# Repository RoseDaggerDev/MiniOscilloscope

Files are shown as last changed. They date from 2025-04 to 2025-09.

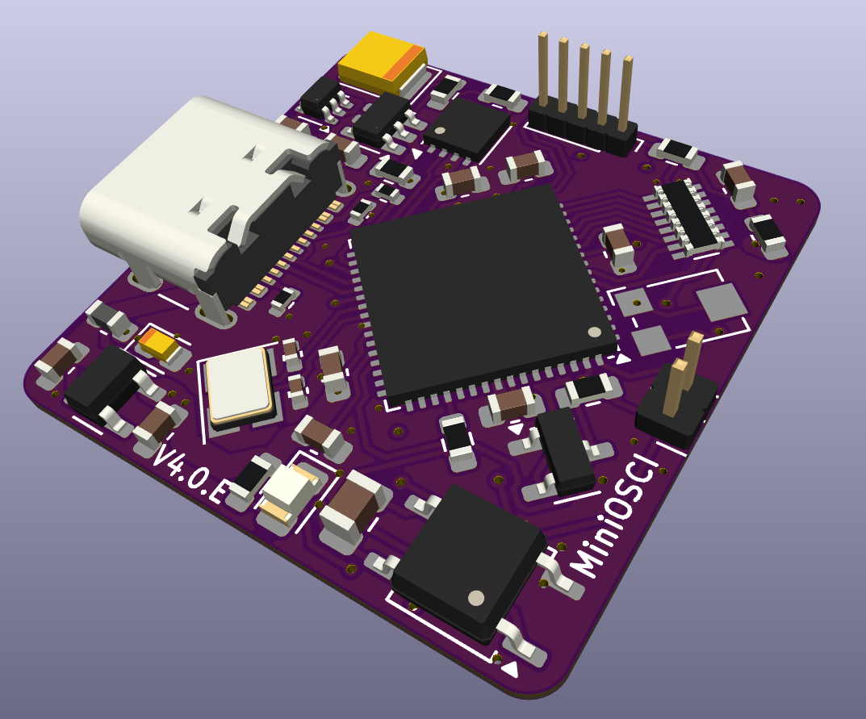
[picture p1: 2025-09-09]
KiCAD/Images/TopRender.png

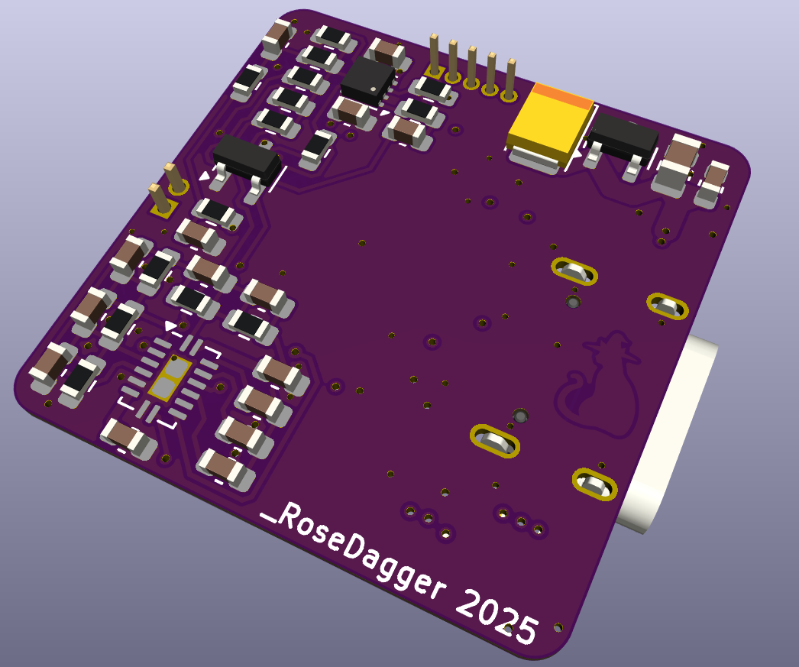
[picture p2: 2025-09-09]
KiCAD/Images/BottomRender.png

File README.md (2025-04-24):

# MiniOscillscope
This is a little hobby project, taking the EDU09 digital oscilloscope kit from Velleman and redesigning it. I made a through-hole version using the same components as the Velleman kit. And a SMD version using all original parts.

Through-Hole Version: Its been fully tested and works like a charm. Its got a BOM of 87 components and fits on a 50x50mm 2-layer board, manufactured by PCBWay. It took around 3.5 hours to solder after prepping all the components. I underestimated the IC socket size, so things got a bit tight with some parts had to be nudged sideways. I also used the wrong footprint size for the ceramic caps, so they’re a little squished, but everything still worked out in the end!

SMD Version: The SMD version is a compact 25x25mm 4-layer board printed by JLCPCB. It has a BOM of 97 components, including 3 QFNs and four 0402-sized parts, the rest mostly 0603s and SOPs. It took me about 5 hours to solder under a digital microscope, using a hot air rework station and freehanded solder paste. There’s one visible bridge in the upper middle that I’ll clean up later. It’s not really an issue as those pins are already connected by a trace, but it will look cleaner. There’s also some solder blobbing that could be tidied up, but hey, it’s functional (or it will be).

Power rails are looking good, 5V and 3.3V are where they should be, and I’ve confirmed there are no shorts or open circuits on the test points. I haven’t flashed firmware yet because it turns out my old PicKit 3 is too old for the PIC I used, so I’m waiting on a new flasher before I can give it a real test.

Background: The through-hole version was a university project, while the SMD version was my own follow-up challenge. I reverse-engineered the component choices from the original Velleman oscilloscope kit, looking up datasheets and selecting alternatives with similar or improved specs. The original Velleman was around 100x100mm. My through-hole version shrank it to 50x50mm (¼ the size), and the SMD version again cut that down to 25x25mm, or just 1/16 the original footprint. Everything was designed in Proteus 5, since that’s what we use at university.

All in all, I’m really happy with how this turned out. It’s my first full SMD design and soldering job, and despite a few cosmetic hiccups, I think it came together nicely. The through-hole version could have looked neater, but given the part constraints of only using the Velleman kit parts, I’m proud of how compact I got it

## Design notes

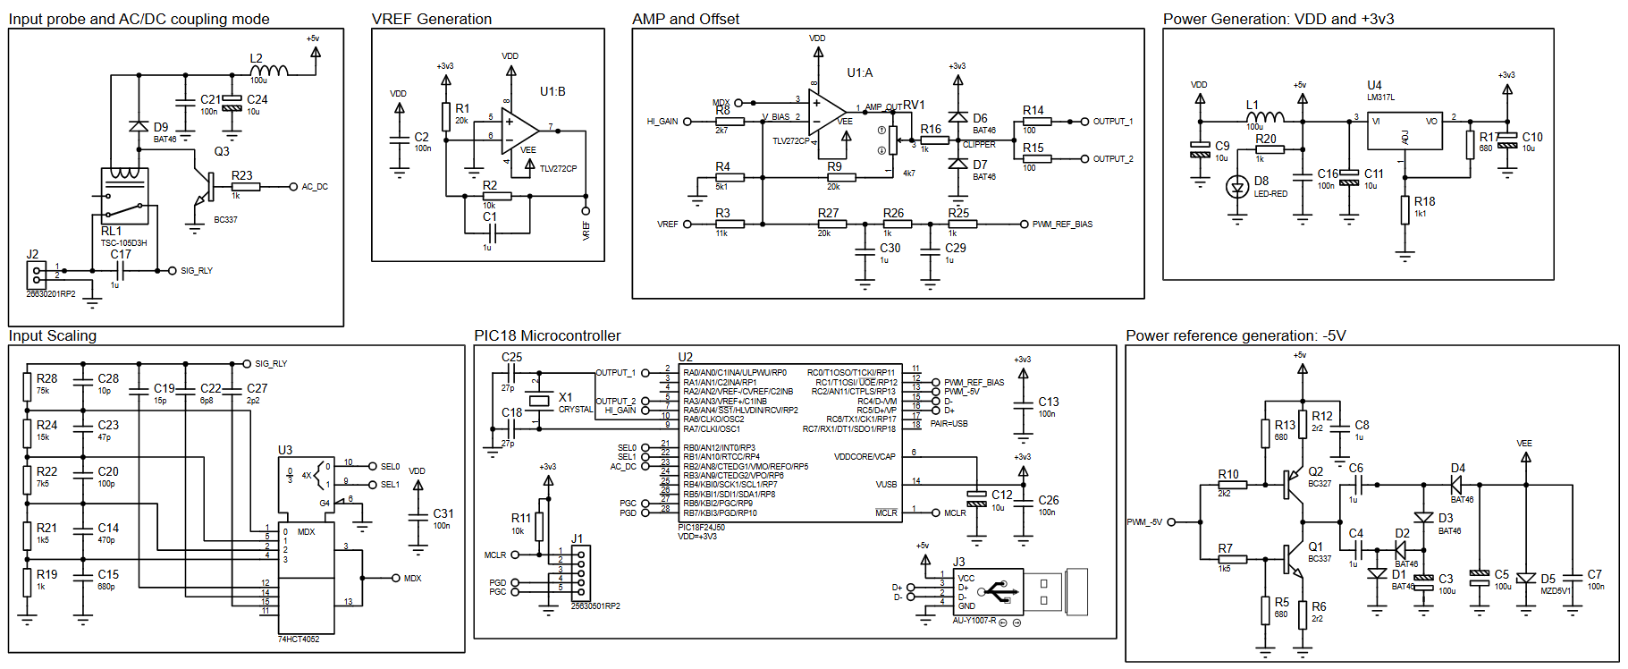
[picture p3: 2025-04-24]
Gloryshots/THT Schematic.png

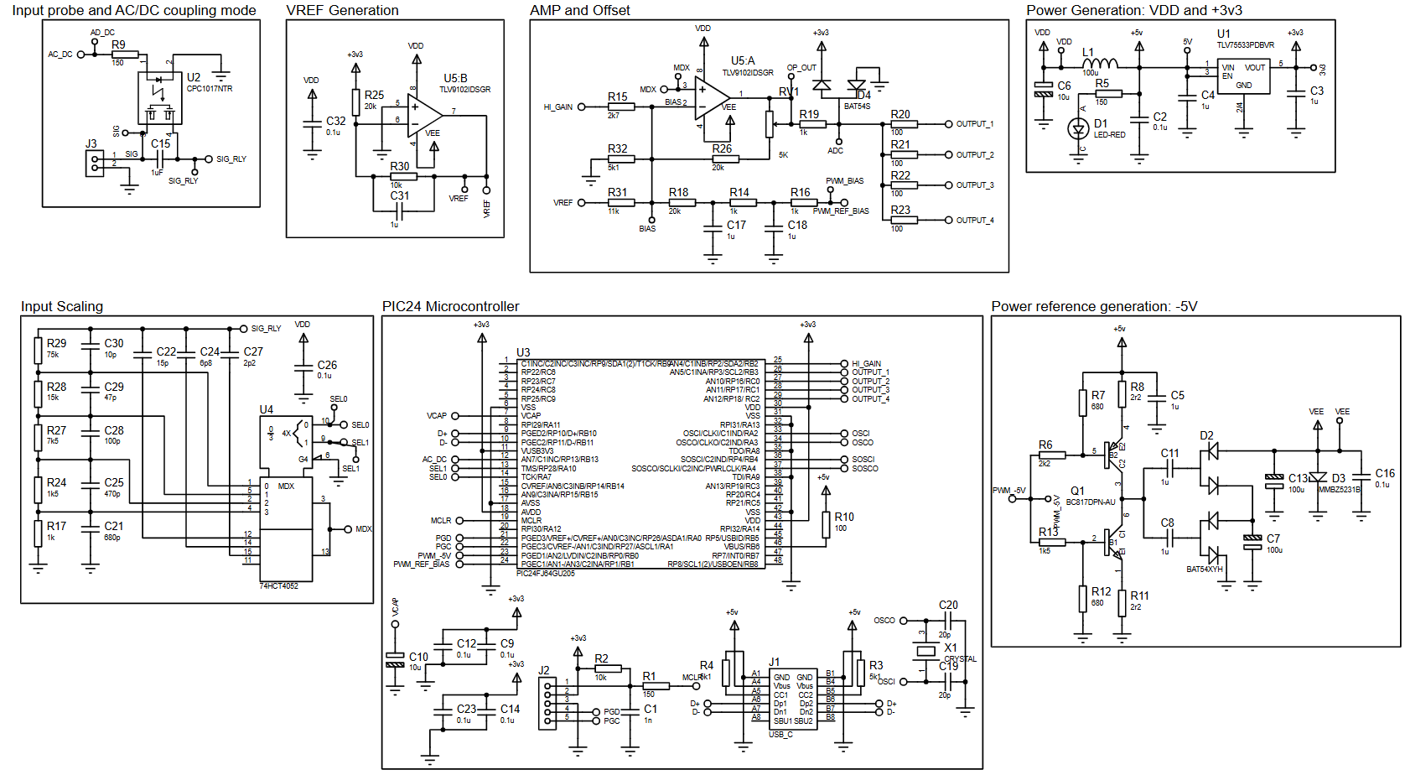
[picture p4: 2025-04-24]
Gloryshots/SMD Schematic.png

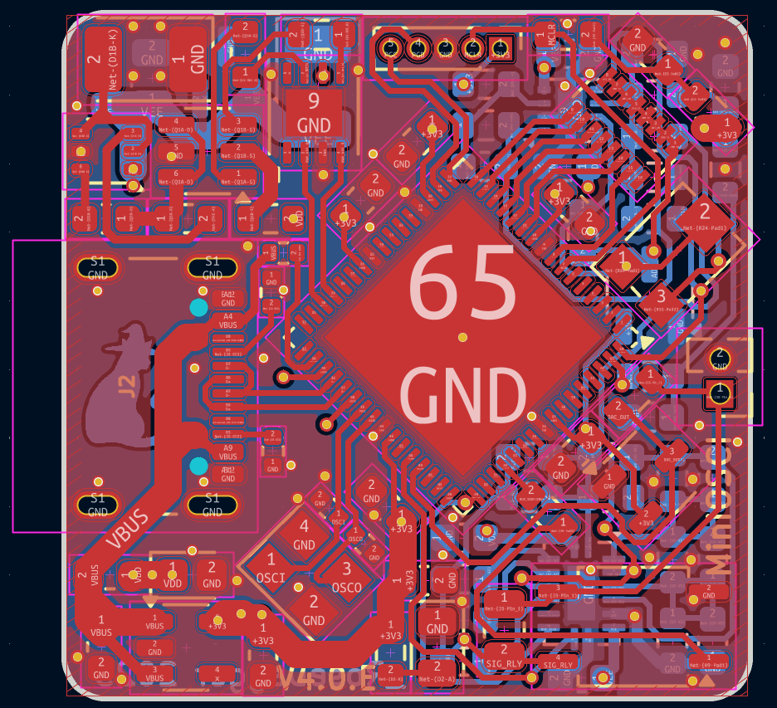
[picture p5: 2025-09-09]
KiCAD/Images/TraceView.png

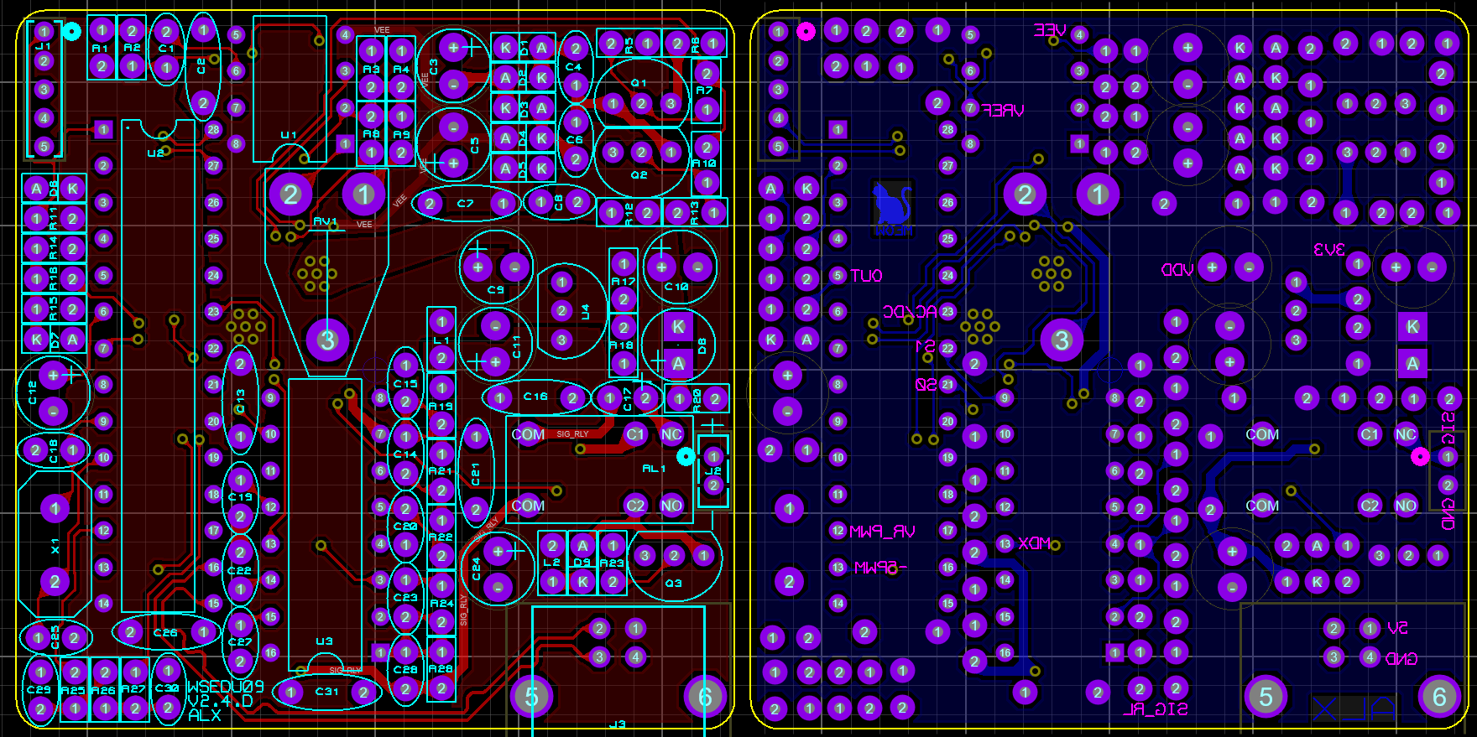
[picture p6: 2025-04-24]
Gloryshots/THT version front back.png

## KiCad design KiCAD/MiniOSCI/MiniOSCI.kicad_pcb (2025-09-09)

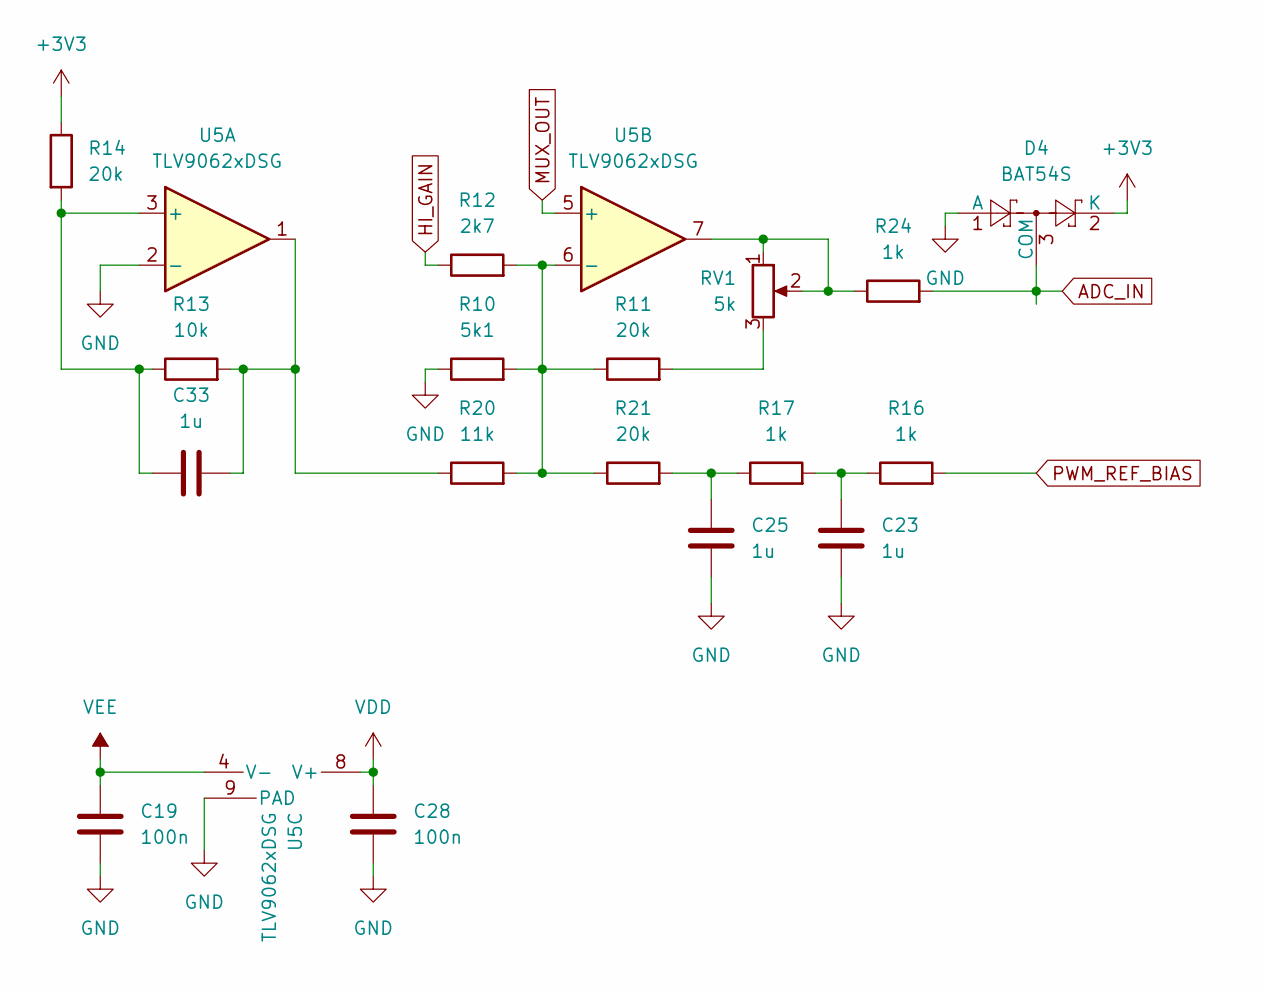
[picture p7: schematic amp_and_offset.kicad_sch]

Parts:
C19, C28: 100n; C_0603_1608Metric
C23, C25, C33: 1u; C_0603_1608Metric
D4: BAT54S; SOT-23-3
R10: 5k1; R_0603_1608Metric
R11, R14, R21: 20k; R_0603_1608Metric
R12: 2k7; R_0603_1608Metric
R13: 10k; R_0603_1608Metric
R16, R17, R24: 1k; R_0603_1608Metric
R20: 11k; R_0603_1608Metric
RV1: 5k; Potentiometer_Bourns_TC33X_Vertical
U5: TLV9062xDSG; WSON-8-1EP_2x2mm_P0.5mm_EP0.9x1.6mm

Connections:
+3V3: D4.2 (K), R14.1; also elsewhere on the board
ADC_IN: D4.3 (COM), R24.2; also elsewhere on the board
GND: C19.2, C23.2, C25.2, C28.2, D4.1 (A), R10.1, U5.2 (-), U5.9 (PAD); also elsewhere on the board
HI_GAIN: R12.1; also elsewhere on the board
MUX_OUT: U5.5 (+); also elsewhere on the board
unnamed: C23.1, R16.1, R17.2
unnamed: C25.1, R17.1, R21.2
unnamed: C33.2, R13.2, R20.1, U5.1
unnamed: R11.2, RV1.3
unnamed: R24.1, RV1.1, RV1.2, U5.7
unnamed: C33.1, R13.1, R14.2, U5.3 (+)
unnamed: R10.2, R11.1, R12.2, R20.2, R21.1, U5.6 (-)
PWM_REF_BIAS: R16.2; also elsewhere on the board
VDD: C28.1, U5.8 (V+); also elsewhere on the board
VEE: C19.1, U5.4 (V-); also elsewhere on the board

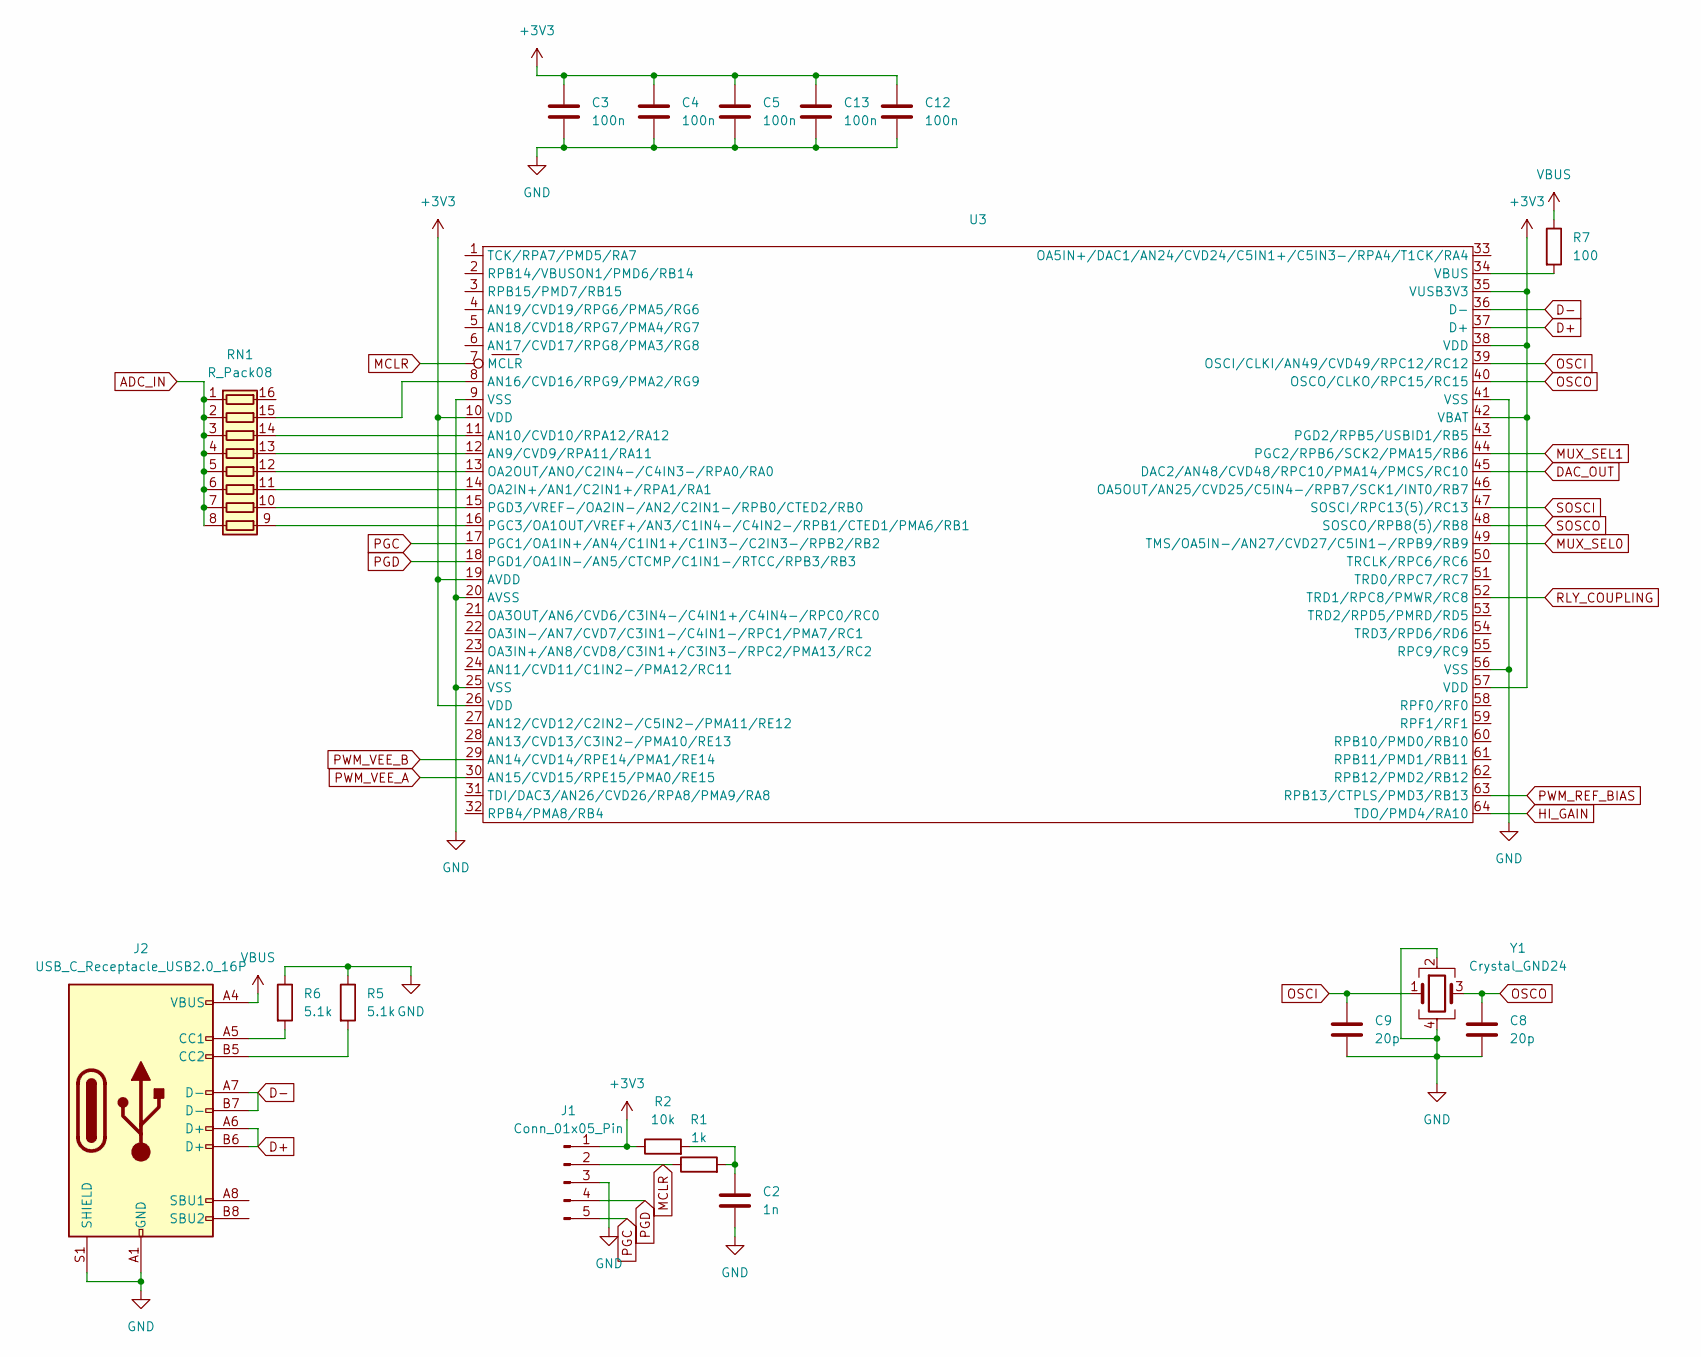
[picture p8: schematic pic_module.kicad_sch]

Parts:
C2: 1n; C_0603_1608Metric
C3, C4, C5, C12, C13: 100n; C_0603_1608Metric
C8, C9: 20p; C_0402_1005Metric
J1: Conn_01x05_Pin; PinHeader_1x05_P1.00mm_Vertical
J2: USB_C_Receptacle_USB2.0_16P; USB_C_Receptacle_GCT_USB4105-xx-A_16P_TopMnt_Horizontal
R1: 1k; R_0603_1608Metric
R2: 10k; R_0603_1608Metric
R5, R6: 5.1k; R_0402_1005Metric
R7: 100; R_0402_1005Metric
RN1: R_Pack08; R_Array_Convex_8x0602
U3: VQFN-64-1EP_9x9mm_P0.5mm_EP7.15x7.15mm
Y1: Crystal_GND24; Crystal_SMD_3225-4Pin_3.2x2.5mm

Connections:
+3V3: C3.1, C4.1, C5.1, C12.1, C13.1, J1.1, R2.1, U3.10 (VDD), U3.19 (AVDD), U3.26 (VDD), U3.35 (VUSB3V3), U3.38 (VDD), U3.42 (VBAT), U3.57 (VDD); also elsewhere on the board
ADC_IN: RN1.1 (R1.1), RN1.2 (R2.1), RN1.3 (R3.1), RN1.4 (R4.1), RN1.5 (R5.1), RN1.6 (R6.1), RN1.7 (R7.1), RN1.8 (R8.1); also elsewhere on the board
D+: J2.A6 (D+), J2.B6 (D+), U3.37 (D+)
D-: J2.A7 (D-), J2.B7 (D-), U3.36 (D-)
DAC_OUT: U3.45 (DAC2/AN48/CVD48/RPC10/PMA14/PMCS/RC10); also elsewhere on the board
GND: C2.2, C3.2, C4.2, C5.2, C8.2, C9.2, C12.2, C13.2, J1.3, J2.A1 (GND), J2.A12 (GND), J2.B1 (GND), J2.B12 (GND), J2.S1 (SHIELD), R5.1, R6.1, U3.9 (VSS), U3.20 (AVSS), U3.25 (VSS), U3.41 (VSS), U3.56 (VSS), U3.65, Y1.2, Y1.4; also elsewhere on the board
HI_GAIN: U3.64 (TDO/PMD4/RA10); also elsewhere on the board
MCLR: J1.2, R1.1, U3.7 (MCLR)
MUX_SEL0: U3.49 (TMS/OA5IN-/AN27/CVD27/C5IN1-/RPB9/RB9); also elsewhere on the board
MUX_SEL1: U3.44 (PGC2/RPB6/SCK2/PMA15/RB6); also elsewhere on the board
unnamed: C2.1, R1.2, R2.2
unnamed: J2.A5 (CC1), R6.2
unnamed: J2.B5 (CC2), R5.2
unnamed: RN1.15 (R2.2), U3.8 (AN16/CVD16/RPG9/PMA2/RG9)
unnamed: RN1.14 (R3.2), U3.11 (AN10/CVD10/RPA12/RA12)
unnamed: RN1.13 (R4.2), U3.12 (AN9/CVD9/RPA11/RA11)
unnamed: RN1.12 (R5.2), U3.13 (OA2OUT/ANO/C2IN4-/C4IN3-/RPA0/RA0)
unnamed: RN1.11 (R6.2), U3.14 (OA2IN+/AN1/C2IN1+/RPA1/RA1)
unnamed: RN1.10 (R7.2), U3.15 (PGD3/VREF-/OA2IN-/AN2/C2IN1-/RPB0/CTED2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)
unnamed: RN1.9 (R8.2), U3.16 (PGC3/OA1OUT/VREF+/AN3/C1IN4-/C4IN2-/RPB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)
unnamed: R7.2, U3.34 (VBUS)
OSCI: C9.1, U3.39 (OSCI/CLKI/AN49/CVD49/RPC12/RC12), Y1.1
OSCO: C8.1, U3.40 (OSCO/CLKO/RPC15/RC15), Y1.3
PGC: J1.5, U3.17 (PGC1/OA1IN+/AN4/C1IN1+/C1IN3-/C2IN3-/RP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)
PGD: J1.4, U3.18 (PGD1/OA1IN-/AN5/CTCMP/C1IN1-/RTCC/RPB3/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)
PWM_REF_BIAS: U3.63 (RPB13/CTPLS/PMD3/RB13); also elsewhere on the board
PWM_VEE_A: U3.30 (AN15/CVD15/RPE15/PMA0/RE15); also elsewhere on the board
PWM_VEE_B: U3.29 (AN14/CVD14/RPE14/PMA1/RE14); also elsewhere on the board
RLY_COUPLING: U3.52 (TRD1/RPC8/PMWR/RC8); also elsewhere on the board
SOSCI: U3.47 (SOSCI/RPC13(5)/RC13)
SOSCO: U3.48 (SOSCO/RPB8(5)/RB8)
VBUS: J2.A4 (VBUS), J2.A9 (VBUS), J2.B4 (VBUS), J2.B9 (VBUS), R7.1; also elsewhere on the board

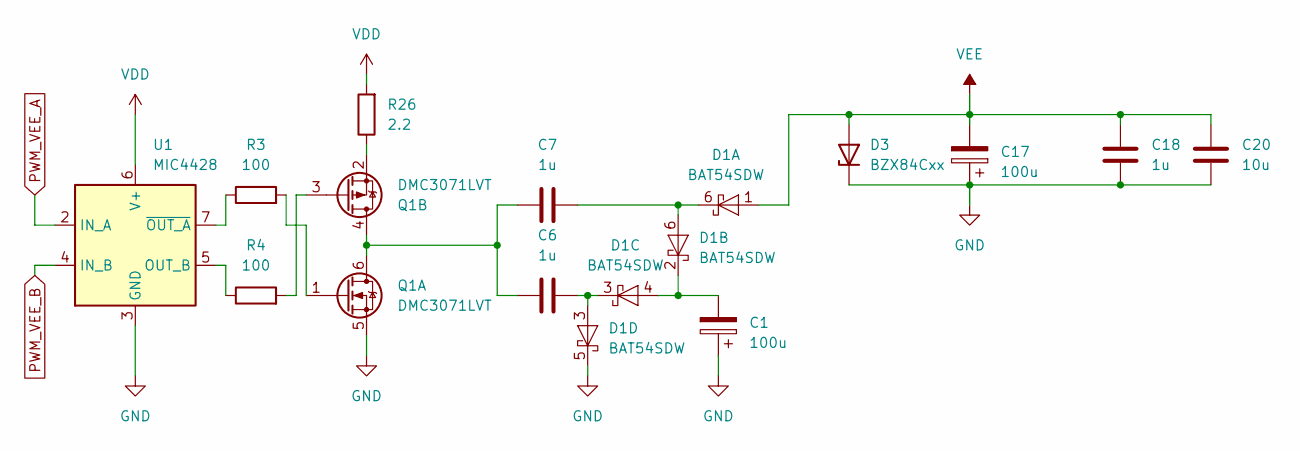
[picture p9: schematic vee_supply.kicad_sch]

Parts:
C1, C17: 100u; CP_EIA-3528-12_Kemet-T
C6, C7, C18: 1u; C_0603_1608Metric
C20: 10u; C_0805_2012Metric
D1: BAT54SDW; SOT-363_SC-70-6
D3: BZX84Cxx; SOT-23
Q1: DMC3071LVT; TSOT-23-6
R3, R4: 100; R_0603_1608Metric
R26: 2.2; R_0603_1608Metric
U1: MIC4428; DFN-8-1EP_3x3mm_P0.65mm_EP1.7x2.05mm

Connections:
GND: C1.1, C17.1, C18.1, C20.2, D1.5 (K), D3.3 (K), Q1.5 (S), U1.3 (GND), U1.9; also elsewhere on the board
unnamed: C7.2, D1.6 (K)
unnamed: C1.2, D1.2 (K), D1.4 (A)
unnamed: C6.2, D1.3 (A)
unnamed: C6.1, C7.1, Q1.4 (D), Q1.6 (D)
unnamed: Q1.1 (G), R3.2
unnamed: Q1.3 (G), R4.2
unnamed: Q1.2 (S), R26.1
unnamed: R4.1, U1.5 (OUT_B)
unnamed: R3.1, U1.7 (~OUT_A)
PWM_VEE_A: U1.2 (IN_A); also elsewhere on the board
PWM_VEE_B: U1.4 (IN_B); also elsewhere on the board
VDD: R26.2, U1.6 (V+); also elsewhere on the board
VEE: C17.2, C18.2, C20.1, D1.1 (A), D3.1 (A); also elsewhere on the board

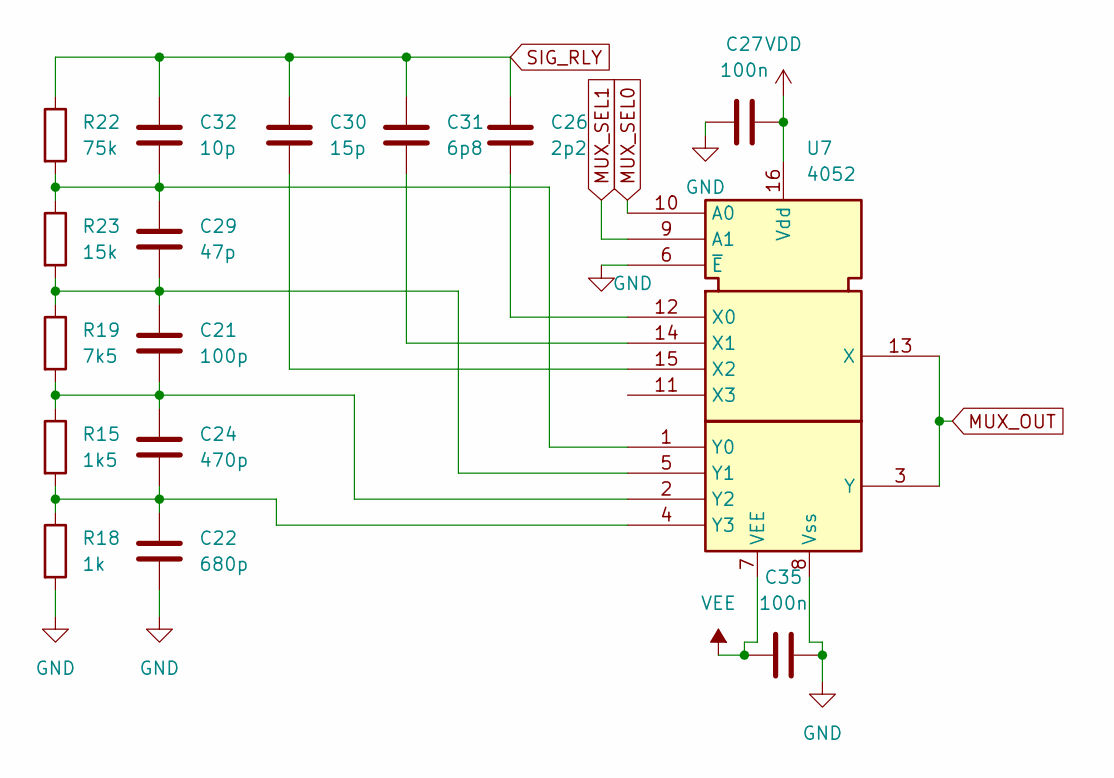
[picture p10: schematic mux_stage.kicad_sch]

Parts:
C21: 100p; C_0603_1608Metric
C22: 680p; C_0603_1608Metric
C24: 470p; C_0603_1608Metric
C26: 2p2; C_0603_1608Metric
C27, C35: 100n; C_0603_1608Metric
C29: 47p; C_0603_1608Metric
C30: 15p; C_0603_1608Metric
C31: 6p8; C_0603_1608Metric
C32: 10p; C_0603_1608Metric
R15: 1k5; R_0603_1608Metric
R18: 1k; R_0603_1608Metric
R19: 7k5; R_0603_1608Metric
R22: 75k; R_0603_1608Metric
R23: 15k; R_0603_1608Metric
U7: 4052; DHVQFN-16-1EP_2.5x3.5mm_P0.5mm_EP1x2mm

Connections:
GND: C22.1, C27.1, C35.2, R18.2, U7.6 (~E), U7.8 (Vss), U7.17; also elsewhere on the board
MUX_OUT: U7.3 (Y), U7.13 (X); also elsewhere on the board
MUX_SEL0: U7.10 (A0); also elsewhere on the board
MUX_SEL1: U7.9 (A1); also elsewhere on the board
unnamed: C26.1, U7.12 (X0)
unnamed: C31.1, U7.14 (X1)
unnamed: C30.1, U7.15 (X2)
unnamed: C29.2, C32.1, R22.2, R23.1, U7.1 (Y0)
unnamed: C21.2, C29.1, R19.1, R23.2, U7.5 (Y1)
unnamed: C21.1, C24.2, R15.1, R19.2, U7.2 (Y2)
unnamed: C22.2, C24.1, R15.2, R18.1, U7.4 (Y3)
SIG_RLY: C26.2, C30.2, C31.2, C32.2, R22.1; also elsewhere on the board
VDD: C27.2, U7.16 (Vdd); also elsewhere on the board
VEE: C35.1, U7.7 (VEE); also elsewhere on the board

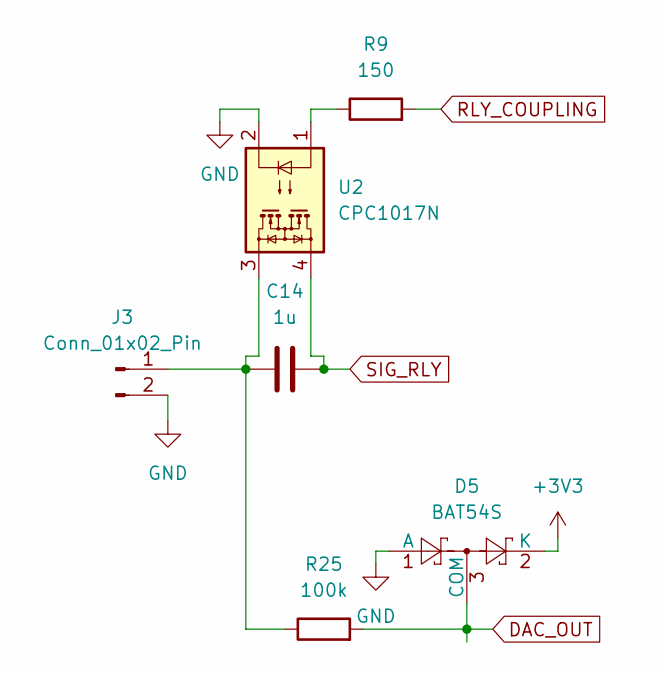
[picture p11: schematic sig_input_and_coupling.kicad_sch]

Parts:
C14: 1u; C_0805_2012Metric
D5: BAT54S; SOT-23-3
J3: Conn_01x02_Pin; PinHeader_1x02_P1.27mm_Vertical
R9: 150; R_0603_1608Metric
R25: 100k; R_0603_1608Metric
U2: CPC1017N; SOP-4_3.8x4.1mm_P2.54mm

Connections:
+3V3: D5.2 (K); also elsewhere on the board
DAC_OUT: D5.3 (COM), R25.2; also elsewhere on the board
GND: D5.1 (A), J3.2, U2.2; also elsewhere on the board
unnamed: C14.1, J3.1, R25.1, U2.3
unnamed: R9.1, U2.1
RLY_COUPLING: R9.2; also elsewhere on the board
SIG_RLY: C14.2, U2.4; also elsewhere on the board

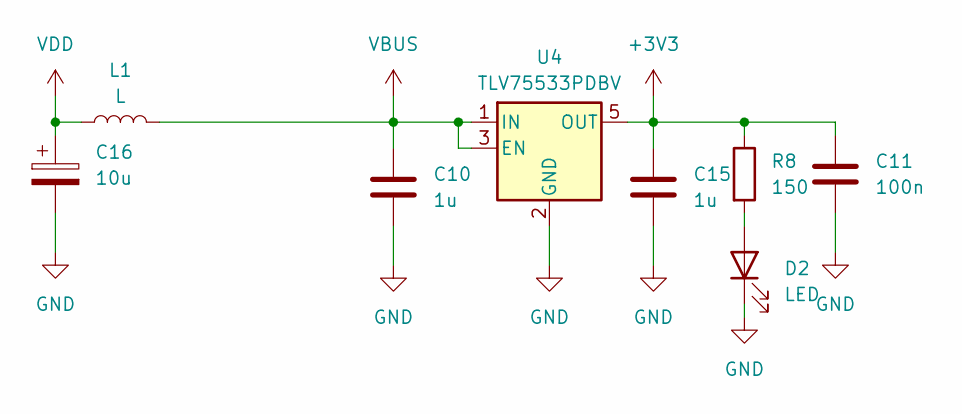
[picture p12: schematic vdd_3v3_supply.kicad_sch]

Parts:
C10, C15: 1u; C_0603_1608Metric
C11: 100n; C_0603_1608Metric
C16: 10u; CP_EIA-1608-08_AVX-J
D2: LED; LED_0805_2012Metric
L1: L; L_0603_1608Metric
R8: 150; R_0603_1608Metric
U4: TLV75533PDBV; SOT-23-5

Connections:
+3V3: C11.1, C15.1, R8.1, U4.5 (OUT); also elsewhere on the board
GND: C10.2, C11.2, C15.2, C16.2, D2.1 (K), U4.2 (GND); also elsewhere on the board
unnamed: D2.2 (A), R8.2
VBUS: C10.1, L1.2, U4.1 (IN), U4.3 (EN); also elsewhere on the board
VDD: C16.1, L1.1; also elsewhere on the board

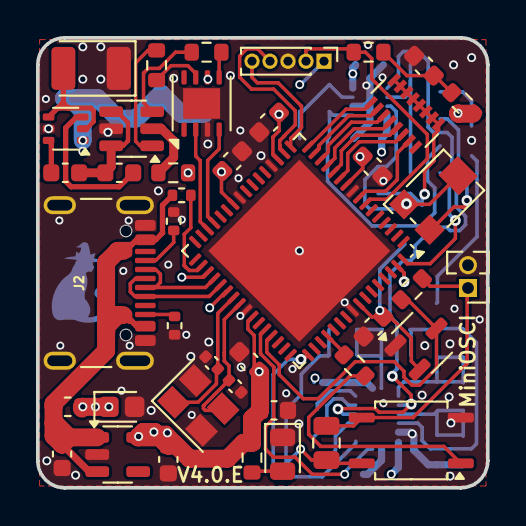
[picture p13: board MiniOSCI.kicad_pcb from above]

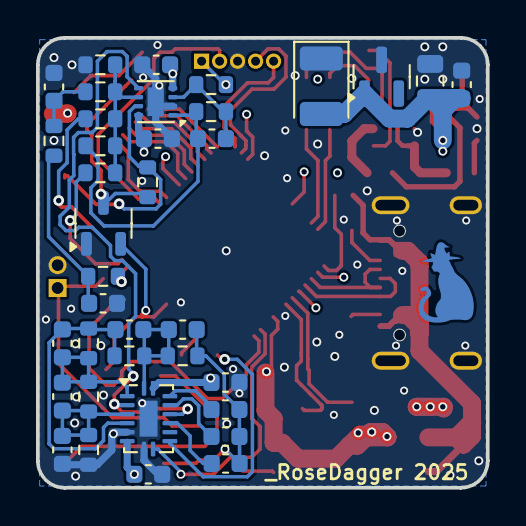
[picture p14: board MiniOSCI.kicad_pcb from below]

Board: 4 copper layers, 25.0 x 25.0 mm, 79 parts (37 on the bottom side), 60 nets.

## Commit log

2025-09-09 Added KiCad version
    [MiniOSCI.kicad_pcb, MiniOSCI.kicad_sch, amp_and_offset.kicad_sch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]
2025-09-09 Added images for kicad version
